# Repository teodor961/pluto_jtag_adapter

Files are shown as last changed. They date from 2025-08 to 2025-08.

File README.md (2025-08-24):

# PLUTO JTAG ADAPTER

JTAG programmer for the PLUTOSDR evaluation kit from ADI.

## Features
- JTAG pins breakout from 1.28mm headers to 2.54 standard header pins for use with platform cable II or other external JTAG
- Integrated FT2232 USB to sync serial controller, to serve as a JTAG + UART host (Still work in progress)

## Known issues:
### v1.0.0 
- VREGOUT and VREGIN should be floating but connected to 1.8V
- VPHY and VPLL connected to 1.8V supply, should be connected to 3.3V through ferrite bead
- FT2232 chip not working due to previously stated issues

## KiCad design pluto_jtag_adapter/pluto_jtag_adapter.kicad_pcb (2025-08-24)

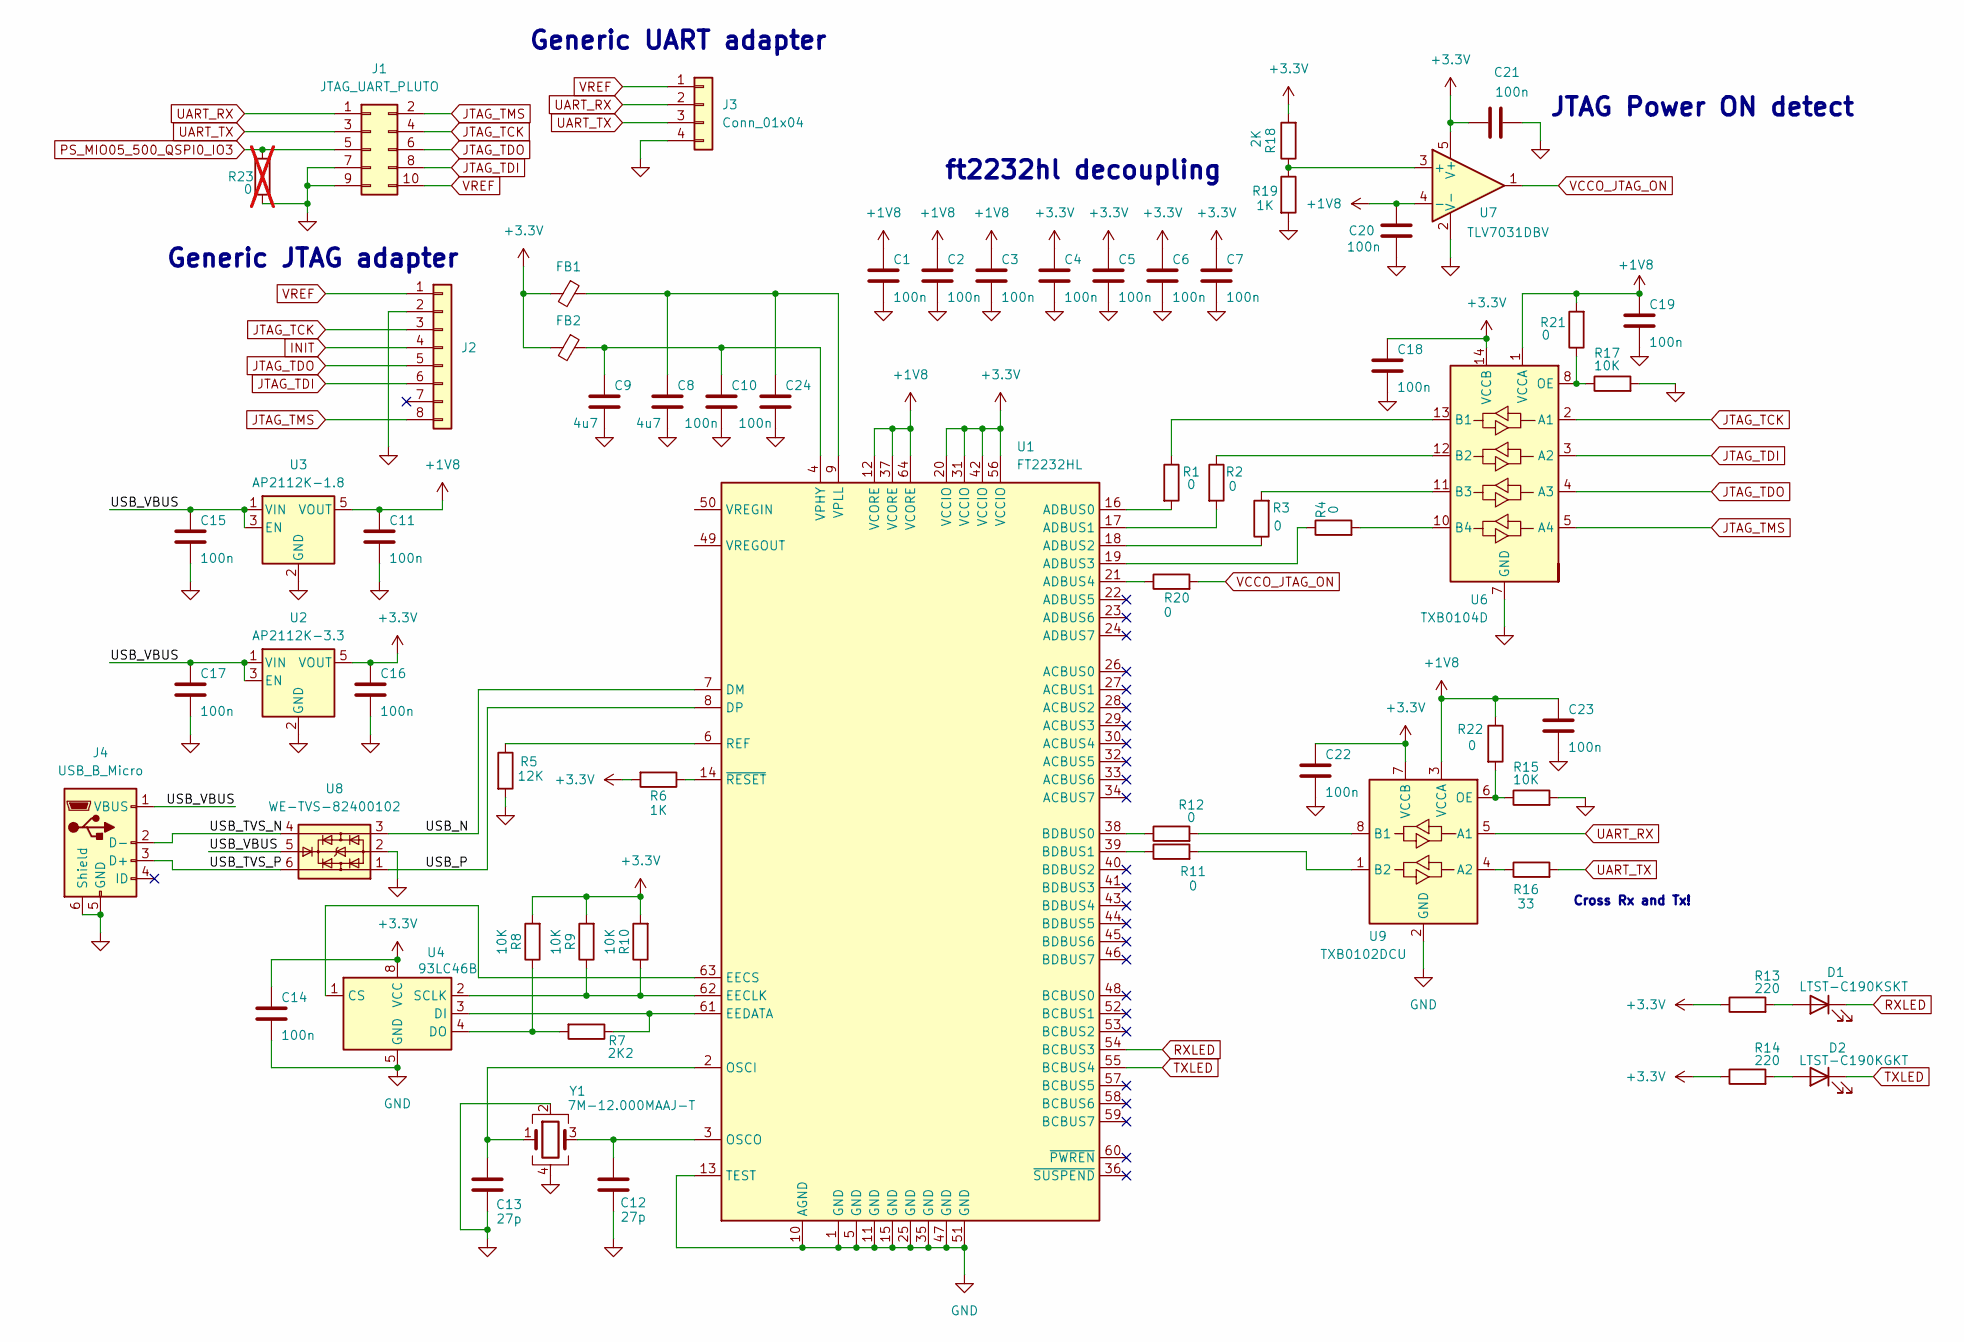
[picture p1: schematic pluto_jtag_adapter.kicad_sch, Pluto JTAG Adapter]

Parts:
C1, C2, C3, C4, C5, C6, C7, C10, C11, C14, C15, C16, C17, C18, C19, C20, C21, C22, C23, C24: 100n; C_0603_1608Metric_Pad1.08x0.95mm_HandSolder
C8, C9: 4u7; C_0603_1608Metric_Pad1.08x0.95mm_HandSolder
C12, C13: 27p; C_0603_1608Metric_Pad1.08x0.95mm_HandSolder
D1: LTST-C190KSKT; LED_0603_1608Metric
D2: LTST-C190KGKT; LED_0603_1608Metric
FB1, FB2: BLM18BA121SH1D; L_0603_1608Metric
J1: JTAG_UART_PLUTO; PinHeader_2x05_P1.27mm_Vertical
J2: Conn_01x08; PinHeader_1x08_P2.54mm_Vertical
J3: Conn_01x04; PinHeader_1x04_P2.54mm_Vertical
J4: USB_B_Micro; USB_Micro-B_Molex_47346-0001
R1, R2, R3, R4, R11, R12, R20, R21, R22: 0; R_0603_1608Metric_Pad0.98x0.95mm_HandSolder
R5: 12K; R_0603_1608Metric_Pad0.98x0.95mm_HandSolder
R6, R19: 1K; R_0603_1608Metric_Pad0.98x0.95mm_HandSolder
R7: 2K2; R_0603_1608Metric_Pad0.98x0.95mm_HandSolder
R8, R9, R10, R15, R17: 10K; R_0603_1608Metric_Pad0.98x0.95mm_HandSolder
R13, R14: 220; R_0603_1608Metric_Pad0.98x0.95mm_HandSolder
R16: 33; R_0603_1608Metric_Pad0.98x0.95mm_HandSolder
R18: 2K; R_0603_1608Metric_Pad0.98x0.95mm_HandSolder
R23: 0; R_0603_1608Metric_Pad0.98x0.95mm_HandSolder; not fitted
U1: FT2232HL; LQFP-64_10x10mm_P0.5mm
U2: AP2112K-3.3; SOT-23-5
U3: AP2112K-1.8; SOT-23-5
U4: 93LC46B; SOIC-8_3.9x4.9mm_P1.27mm
U6: TXB0104D; SOIC-14_3.9x8.7mm_P1.27mm
U7: TLV7031DBV; SOT-23-5
U8: WE-TVS-82400102; SOT-23-6
U9: TXB0102DCU; VSSOP-8_2.3x2mm_P0.5mm
Y1: 7M-12.000MAAJ-T; Crystal_SMD_3225-4Pin_3.2x2.5mm_HandSoldering

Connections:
+1V8: C1.1, C2.1, C3.1, C11.1, C19.1, C20.1, C23.1, R21.2, R22.1, U1.12 (VCORE), U1.37 (VCORE), U1.64 (VCORE), U3.5 (VOUT), U6.1 (VCCA), U7.4 (-), U9.3 (VCCA)
+3.3V: C4.1, C5.1, C6.1, C7.1, C14.1, C16.1, C18.1, C21.1, C22.1, FB1.2, FB2.2, R6.2, R8.2, R9.2, R10.2, R13.1, R14.1, R18.2, U1.20 (VCCIO), U1.31 (VCCIO), U1.42 (VCCIO), U1.56 (VCCIO), U2.5 (VOUT), U4.8 (VCC), U6.14 (VCCB), U7.5 (V+), U9.7 (VCCB)
/USB_N: U1.7 (DM), U8.3
/USB_P: U1.8 (DP), U8.1
/USB_TVS_N: J4.2 (D-), U8.4
/USB_TVS_P: J4.3 (D+), U8.6
/USB_VBUS: C15.1, C17.1, J4.1 (VBUS), U2.1 (VIN), U2.3 (EN), U3.1 (VIN), U3.3 (EN), U8.5
GND: C1.2, C2.2, C3.2, C4.2, C5.2, C6.2, C7.2, C8.2, C9.2, C10.2, C11.2, C12.1, C13.1, C14.2, C15.2, C16.2, C17.2, C18.2, C19.2, C20.2, C21.2, C22.2, C23.2, C24.2, J1.7, J1.9, J2.2, J3.4, J4.5 (GND), J4.6 (Shield), R5.2, R15.2, R17.2, R19.2, R23.1, U1.1 (GND), U1.5 (GND), U1.10 (AGND), U1.11 (GND), U1.13 (TEST), U1.15 (GND), U1.25 (GND), U1.35 (GND), U1.47 (GND), U1.51 (GND), U2.2 (GND), U3.2 (GND), U4.5 (GND), U6.7 (GND), U7.2 (V-), U8.2, U9.2 (GND), Y1.2, Y1.4
INIT: J2.4
JTAG_TCK: J1.4, J2.3, U6.2 (A1)
JTAG_TDI: J1.8, J2.6, U6.3 (A2)
JTAG_TDO: J1.6, J2.5, U6.4 (A3)
JTAG_TMS: J1.2, J2.8, U6.5 (A4)
unnamed: D1.2 (A), R13.2
unnamed: D2.2 (A), R14.2
unnamed: R1.2, U1.16 (ADBUS0)
unnamed: R2.2, U1.17 (ADBUS1)
unnamed: R3.1, U1.18 (ADBUS2)
unnamed: R4.1, U1.19 (ADBUS3)
unnamed: R20.1, U1.21 (ADBUS4)
unnamed: R12.1, U1.38 (BDBUS0)
unnamed: R11.1, U1.39 (BDBUS1)
unnamed: R9.1, R10.1, U1.62 (EECLK), U4.2 (SCLK)
unnamed: U1.63 (EECS), U4.1 (CS)
unnamed: R7.1, U1.61 (EEDATA), U4.3 (DI)
unnamed: C13.2, U1.2 (OSCI), Y1.1
unnamed: C12.2, U1.3 (OSCO), Y1.3
unnamed: R5.1, U1.6 (REF)
unnamed: C9.1, C10.1, FB2.1, U1.4 (VPHY)
unnamed: C8.1, C24.1, FB1.1, U1.9 (VPLL)
unnamed: R6.1, U1.14 (~RESET)
unnamed: R7.2, R8.1, U4.4 (DO)
unnamed: R1.1, U6.13 (B1)
unnamed: R2.1, U6.12 (B2)
unnamed: R3.2, U6.11 (B3)
unnamed: R4.2, U6.10 (B4)
unnamed: R17.1, R21.1, U6.8 (OE)
unnamed: R18.1, R19.1, U7.3 (+)
unnamed: R16.1, U9.4 (A2)
unnamed: R12.2, U9.8 (B1)
unnamed: R11.2, U9.1 (B2)
unnamed: R15.1, R22.2, U9.6 (OE)
PS_MIO05_500_QSPI0_IO3: J1.5, R23.2
RXLED: D1.1 (K), U1.54 (BCBUS3)
TXLED: D2.1 (K), U1.55 (BCBUS4)
UART_RX: J1.1, J3.2, U9.5 (A1)
UART_TX: J1.3, J3.3, R16.2
VCCO_JTAG_ON: R20.2, U7.1
VREF: J1.10, J2.1, J3.1

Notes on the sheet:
Cross Rx and Tx!
Generic JTAG adapter
ft2232hl decoupling
JTAG Power ON detect
Generic UART adapter

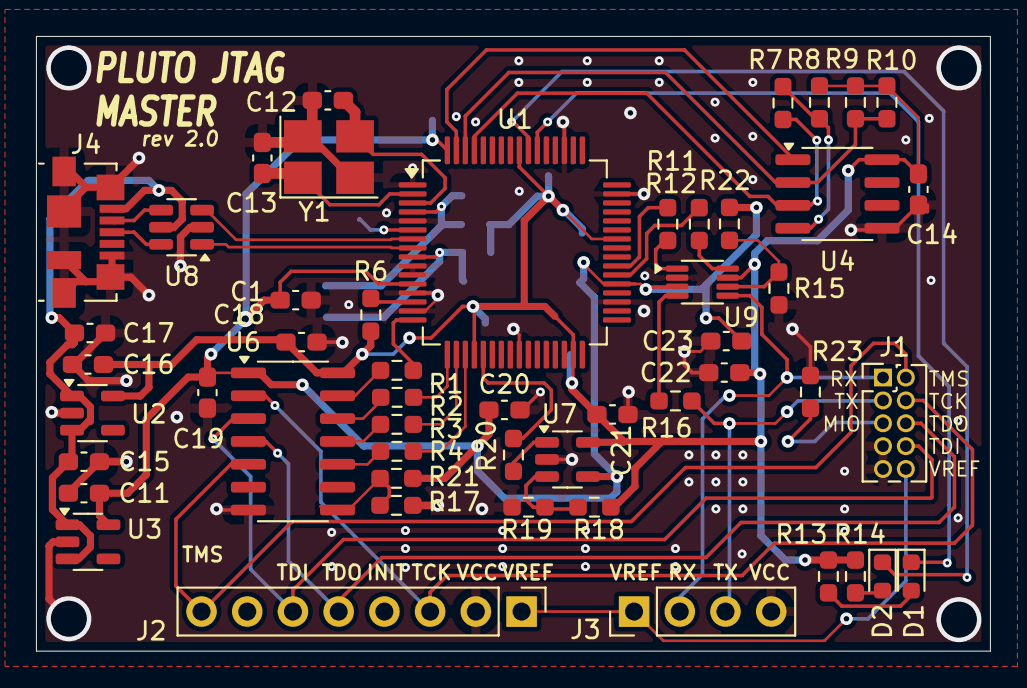
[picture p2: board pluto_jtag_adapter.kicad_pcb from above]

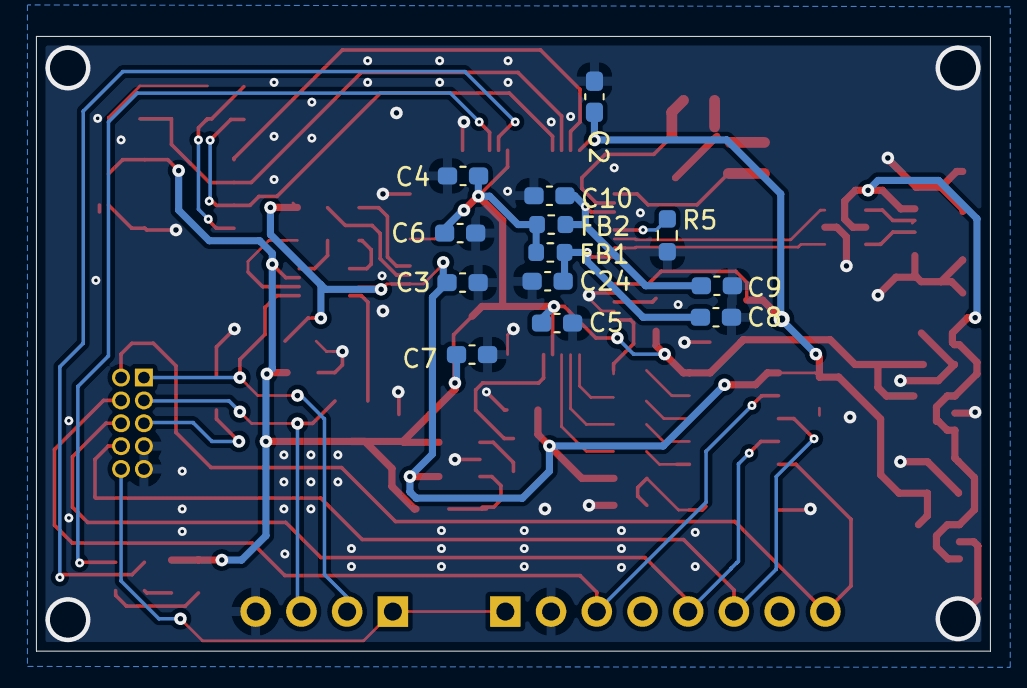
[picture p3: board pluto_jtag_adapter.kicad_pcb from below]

Board: 2 copper layers, 53.0 x 34.2 mm, 64 parts (13 on the bottom side), 48 nets.

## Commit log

2025-04-26 Create schematic first draft
    [pluto_jtag_adapter.kicad_pcb, pluto_jtag_adapter.kicad_sch]
2025-04-28 Add EEPROM and level shifters for ft2232hl chip
    [pluto_jtag_adapter.kicad_sch]
2025-04-28 Assign footprints to components. Wire up OE on level shifters
    [pluto_jtag_adapter.kicad_sch]
2025-04-28 Replace TXS level shifters with TXB (push-pull better for my application)
    [pluto_jtag_adapter.kicad_sch]
2025-04-28 Create PCB floorplan
    [pluto_jtag_adapter.kicad_pcb]
2025-05-04 Clean up PCB layout, add mounting holes and header pin names
    [pluto_jtag_adapter.kicad_pcb, pluto_jtag_adapter.kicad_sch]
2025-05-10 Clean up layout based on first round of design feedback
    [pluto_jtag_adapter.kicad_pcb]
2025-05-12 Add ground fill on top layer. Improve ground fill around signals
    [pluto_jtag_adapter.kicad_pcb, pluto_jtag_adapter.kicad_sch]
2025-05-13 Move oscillator caps closer to oscillator
    [pluto_jtag_adapter.kicad_pcb]
2025-05-15 Replace obsolete component TXB0102DCT with TXB0102DCU
    [pluto_jtag_adapter.kicad_pcb, pluto_jtag_adapter.kicad_sch]
2025-08-24 Disconnect VREGIN and VREGOUT
    [pluto_jtag_adapter.kicad_pcb, pluto_jtag_adapter.kicad_sch]
2025-08-24 Clean up back silkscreeen
    [pluto_jtag_adapter.kicad_pcb]
2025-08-24 Add correct supplies for VPHY and VPLL
    [pluto_jtag_adapter.kicad_pcb, pluto_jtag_adapter.kicad_sch]
